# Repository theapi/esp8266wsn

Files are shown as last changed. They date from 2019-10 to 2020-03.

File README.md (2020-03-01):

# esp8266WSN

ESP8266 Wireless Sensor Network 

## Transmitter
Soil moisture sensors that transmit their data to the ESPNOW network.

- [Hardware](./transmitter/hardware)
- [Schematic](./transmitter/hardware/transmitter.pdf)
- [Software](./transmitter/software)

## Receiver
The receiver for the ESPNOW network, which sends the data to the network bridge.

- [Hardware](./receiver/hardware)
- [Software](./receiver/sfotware)

## Network Bridge
Connects the ESPNOW network to the WiFi network.

- [Software](./network_bridge)

## Monitor
Very basic UDP message listeners are provided in this repo:

- [C](./monitor/c)
- [php](./monitor/php)

A more sophisticated monitor is the [WSN Monitor](https://gitlab.com/theapi/wsn_monitor_sdl)

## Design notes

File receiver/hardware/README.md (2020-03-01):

# Hardware

- [Schematic](./kicad/receiver/receiver.pdf)
- [Datasheets](./datasheets)

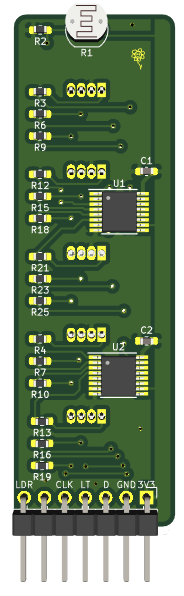
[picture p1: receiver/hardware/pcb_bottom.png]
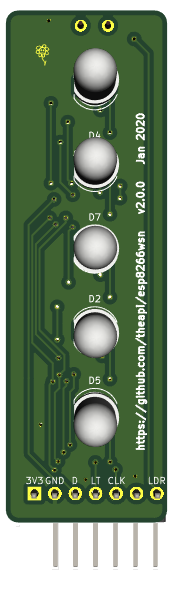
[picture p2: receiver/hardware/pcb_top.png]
 

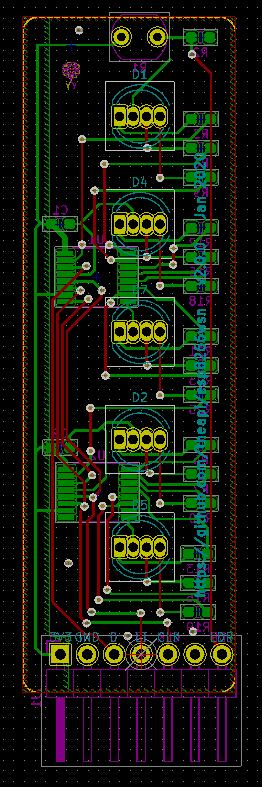
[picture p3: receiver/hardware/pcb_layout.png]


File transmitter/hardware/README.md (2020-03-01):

# Transmitter Hardware

[Schematic](./transmitter.pdf)

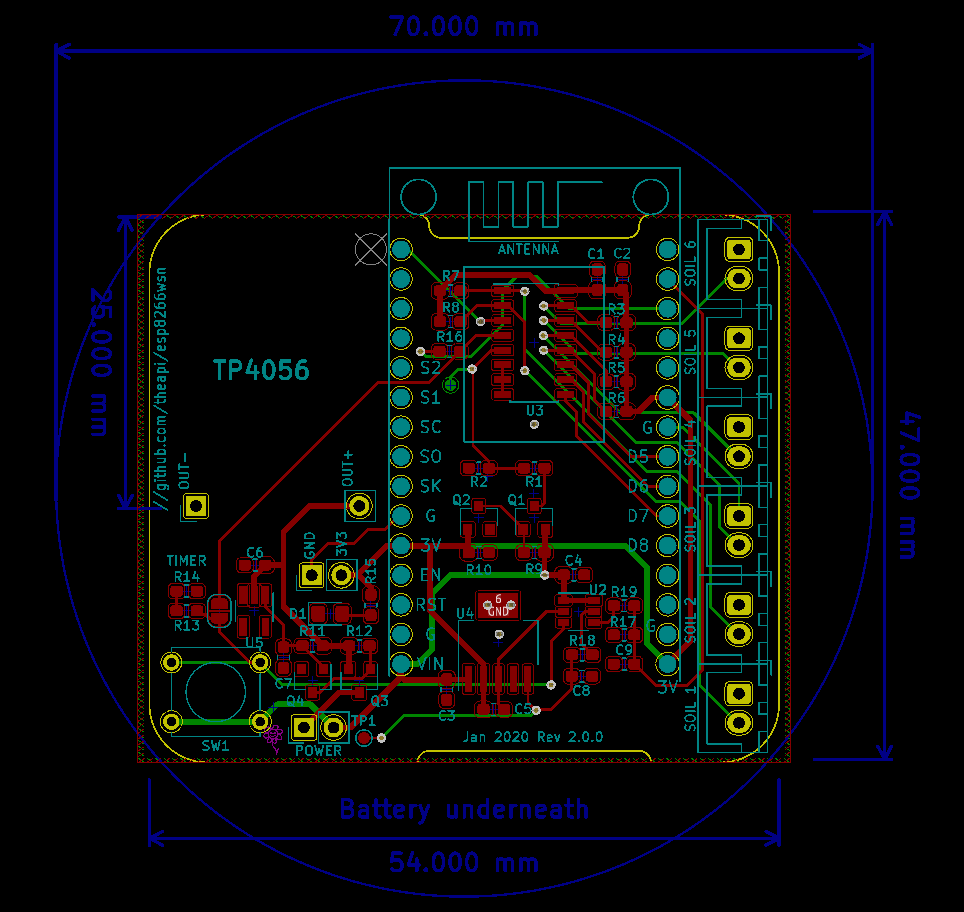
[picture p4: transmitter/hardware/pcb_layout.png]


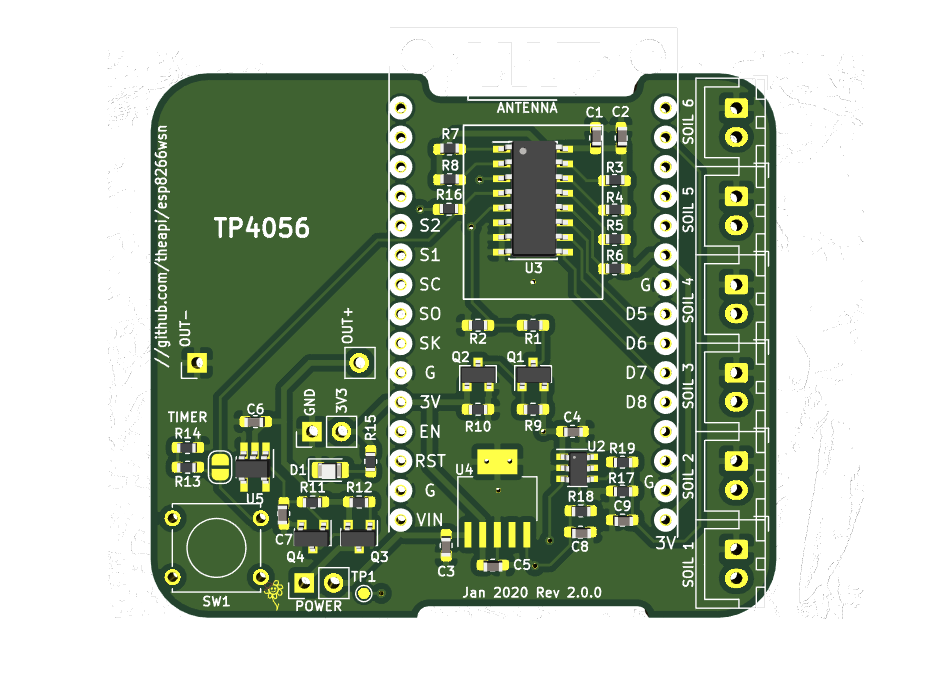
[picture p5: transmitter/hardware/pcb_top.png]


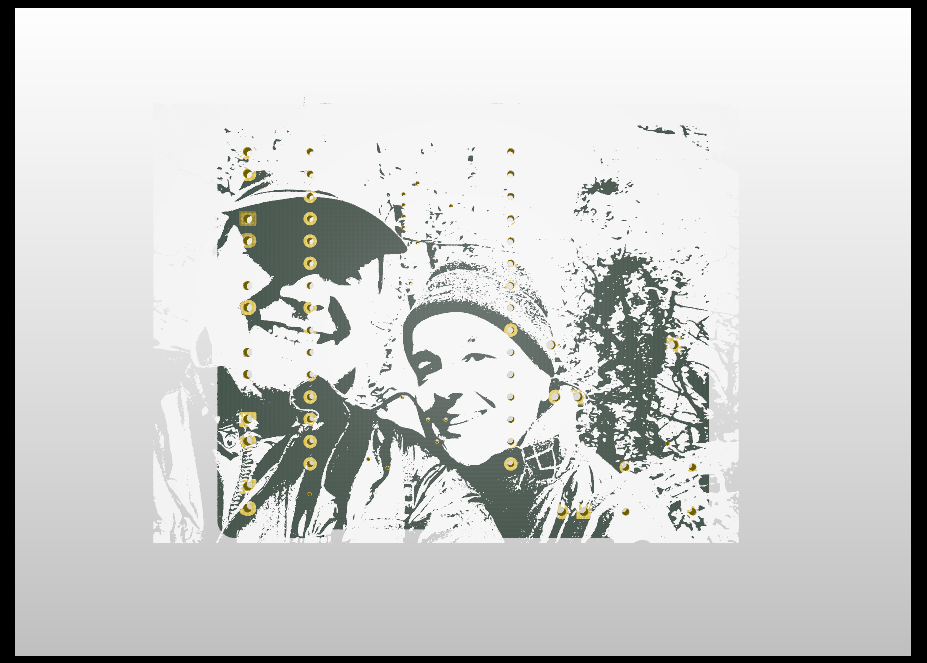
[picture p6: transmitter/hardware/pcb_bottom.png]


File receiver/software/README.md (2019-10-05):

# WSN Receiver

Listens for broadcast data on the ESPNow network.

## How to use

### Hardware Required

* Connection:

| Signal |NODE MCU| Master |
|---|---|---|
| SCLK | D5 | GPIO14 |
| MOSI | D7 | GPIO13 |
| CS | D8 | GPIO15 |
| GND | GND | GND |

### Configure the project

```
make menuconfig
```

* Set serial port under Serial Flasher Options.

### Build and Flash

Build the project and flash it to the board, then run monitor tool to view serial output:

```
make -j4 flash monitor
```

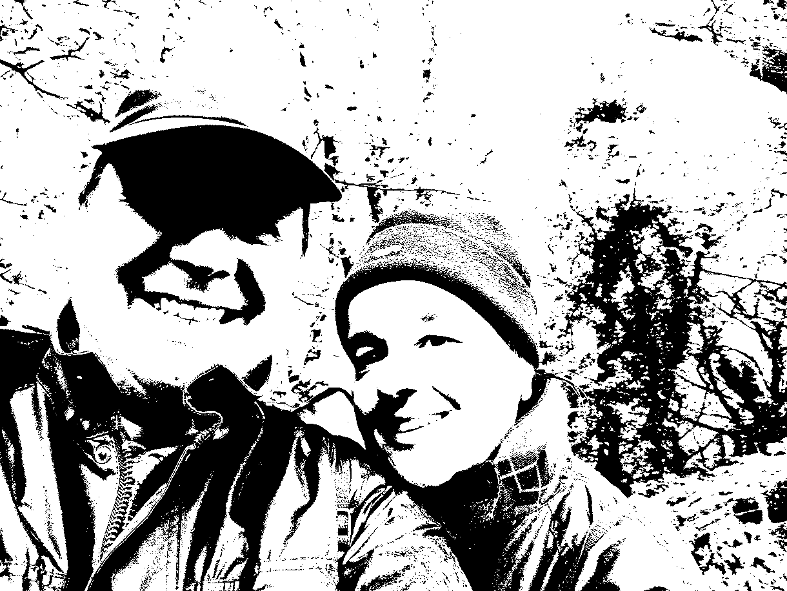
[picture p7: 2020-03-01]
transmitter/hardware/us_bw.png

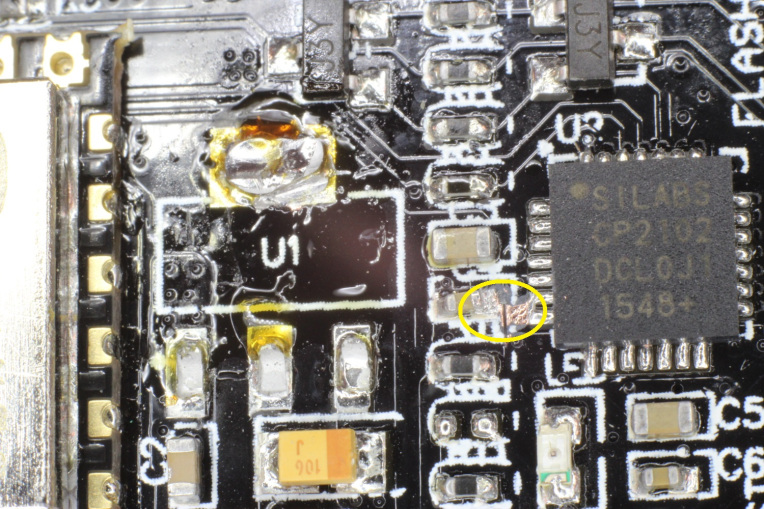
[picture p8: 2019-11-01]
transmitter/datasheets/nodemcu_low_power.jpg

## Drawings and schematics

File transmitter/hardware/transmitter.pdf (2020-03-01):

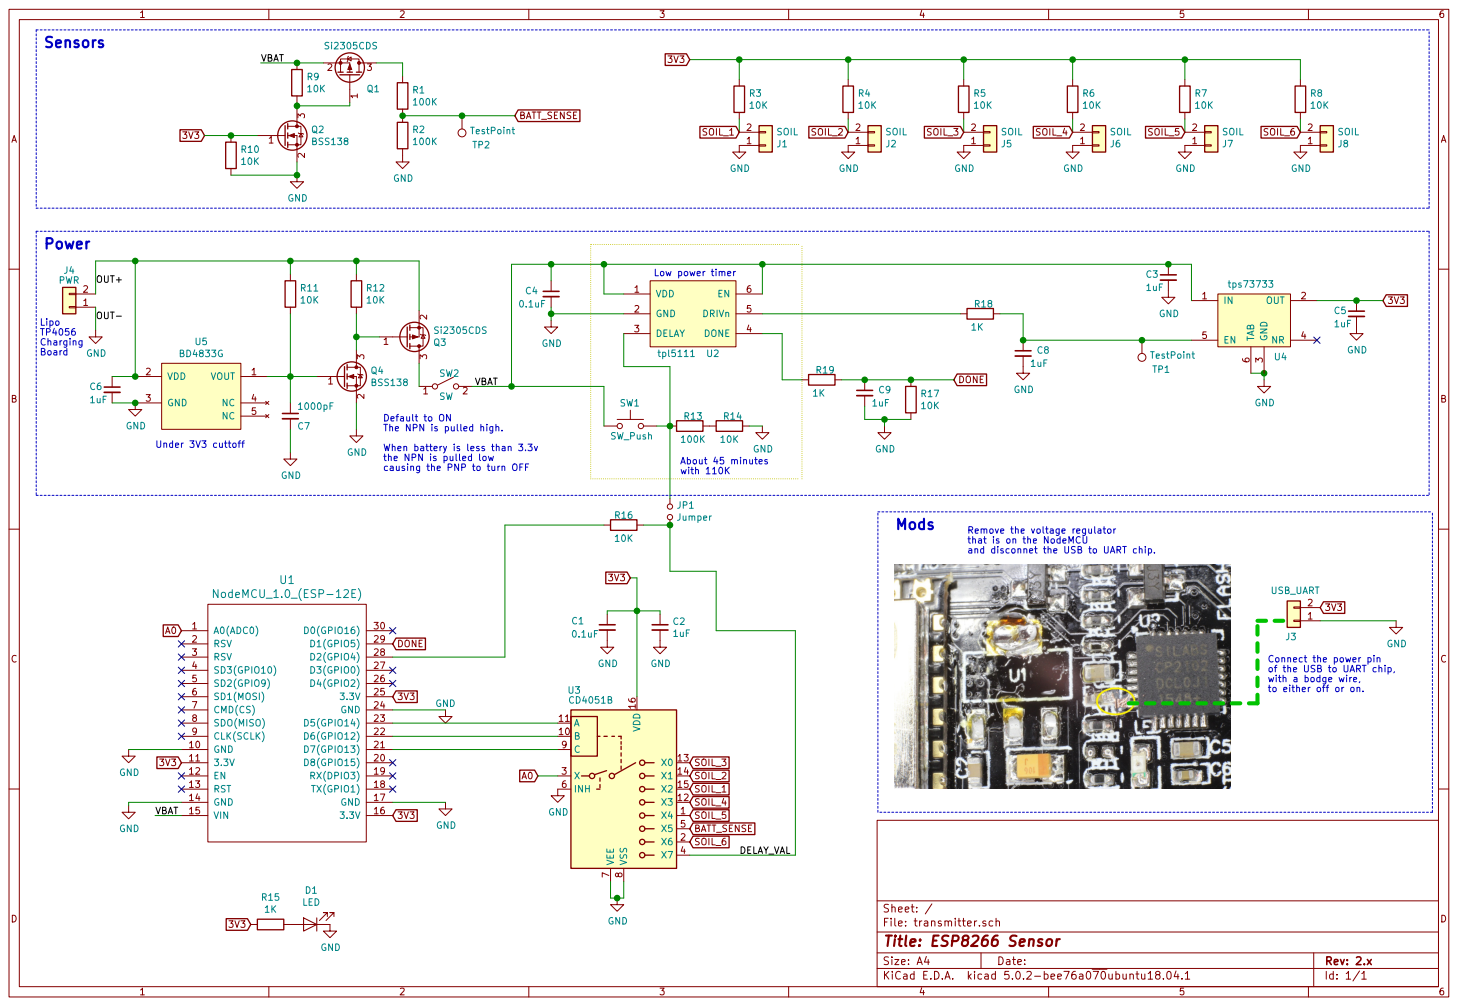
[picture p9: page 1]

2 3 Q3Si2305CDS R12
10KDefault to ON The NPN is pulled high.

When battery is less than 3.3v
the NPN is pulled low
causing the PNP to turn OFF

that is on the NodeMCU
and disconnet the USB to UART chip.

Connect the power pin
of the USB to UART chip,
with a bodge wire,
to either off or on.

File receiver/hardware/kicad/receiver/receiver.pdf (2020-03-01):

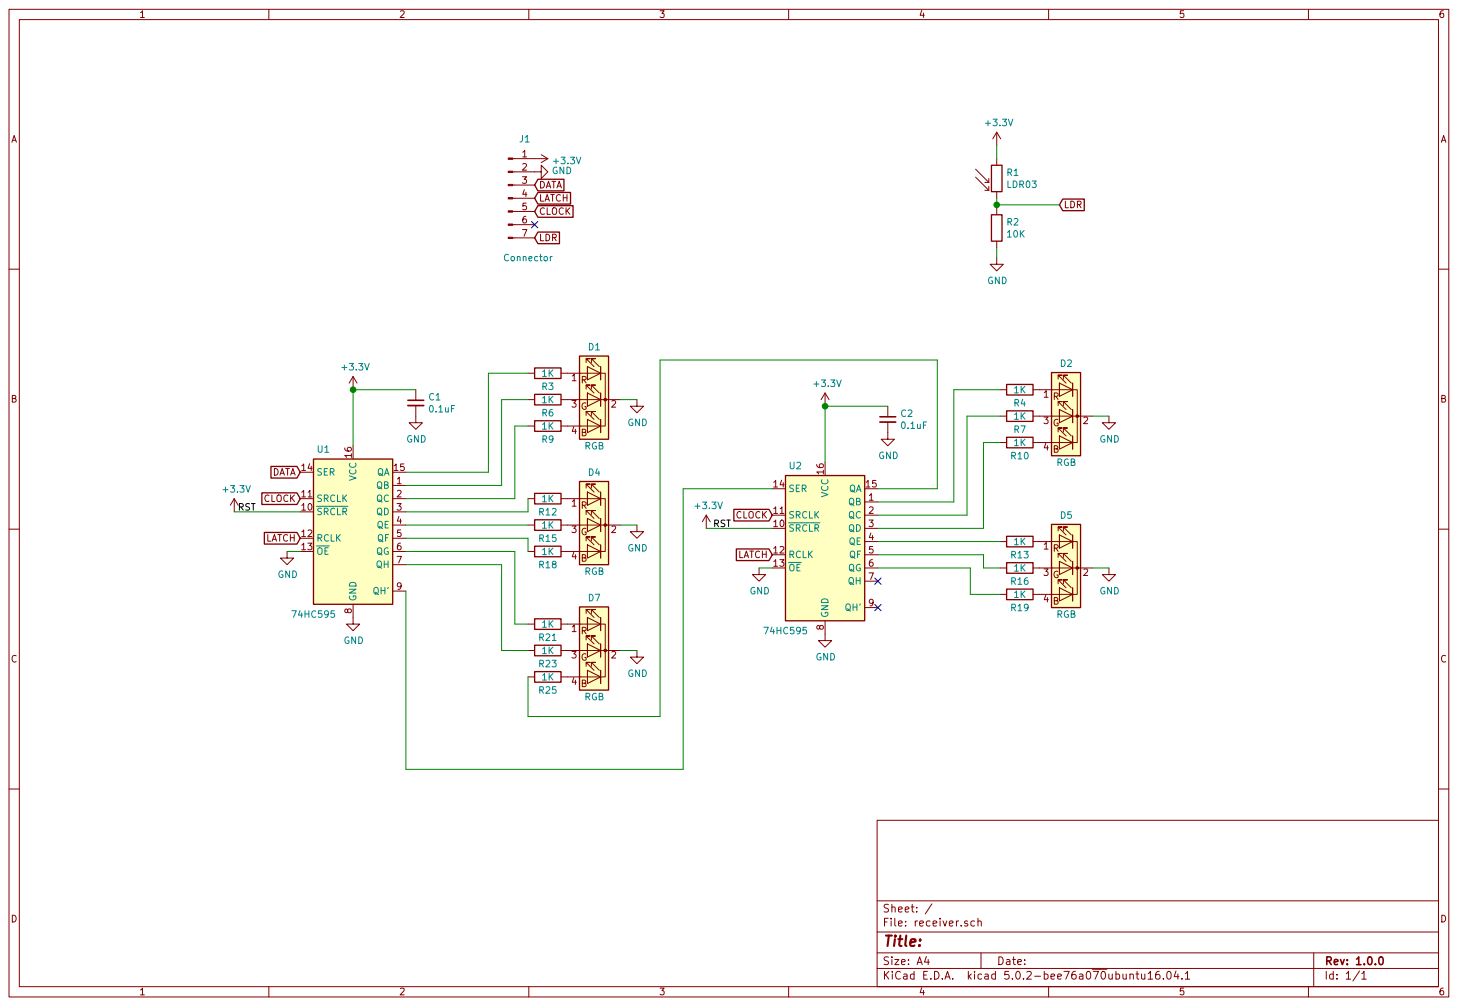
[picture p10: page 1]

Id: 1/1 Title: File: receiver.sch Sheet: /

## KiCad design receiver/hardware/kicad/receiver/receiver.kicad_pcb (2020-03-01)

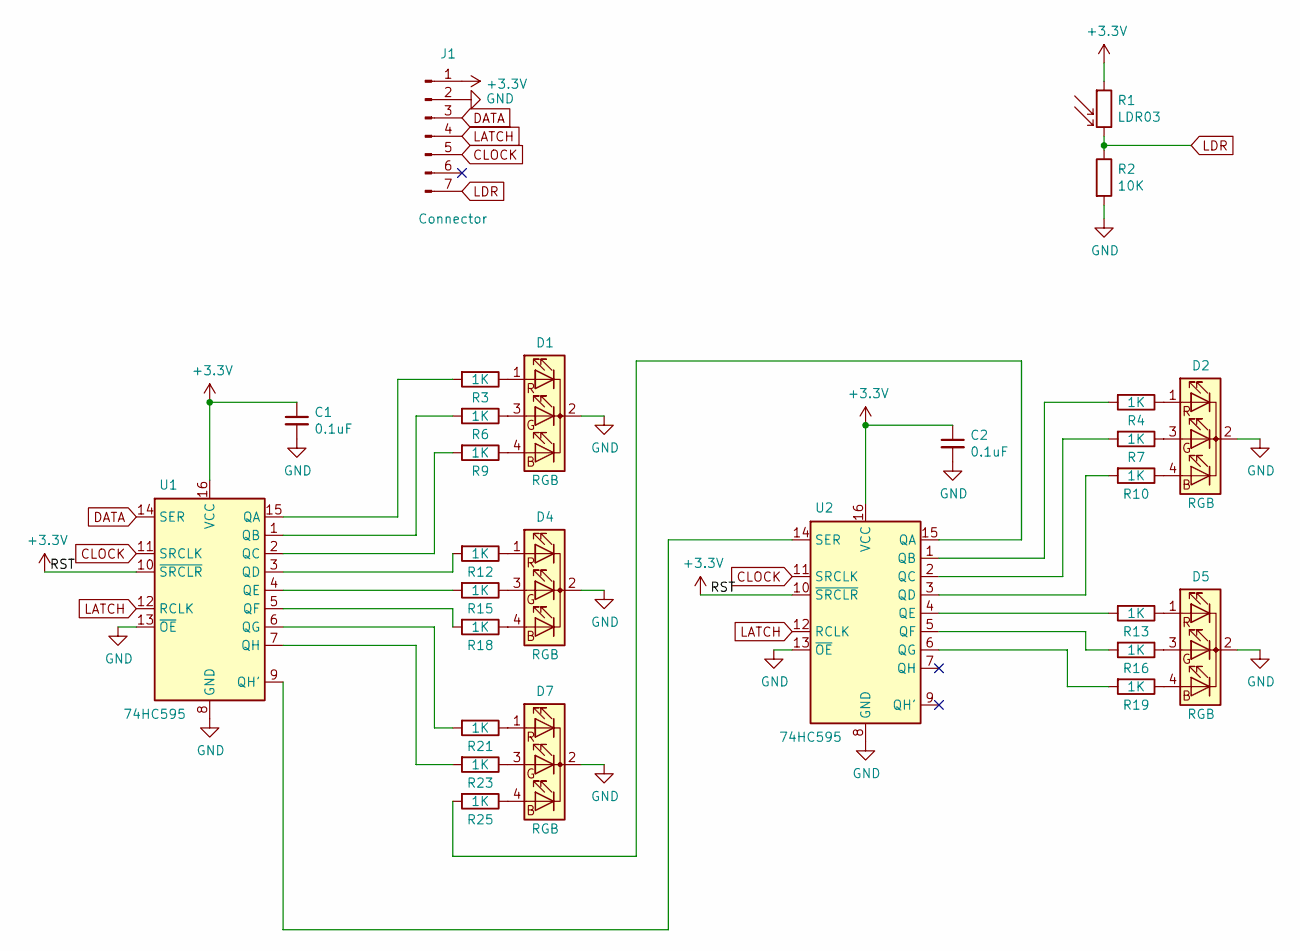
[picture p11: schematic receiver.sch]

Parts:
C1, C2: 0.1uF; C_0603_1608Metric_Pad1.05x0.95mm_HandSolder
D1, D2, D4, D5, D7: RGB; LED_D5.0mm-4_RGB
J1: Connector; PinHeader_1x07_P2.54mm_Horizontal
R1: LDR03; R_LDR_5.1x4.3mm_P3.4mm_Vertical
R2: 10K; R_0603_1608Metric_Pad1.05x0.95mm_HandSolder
R3, R4, R6, R7, R9, R10, R12, R13, R15, R16, R18, R19, R21, R23, R25: 1K; R_0603_1608Metric_Pad1.05x0.95mm_HandSolder
U1, U2: 74HC595; TSSOP-16_4.4x5mm_P0.65mm

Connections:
+3V3: C1.1, C2.1, J1.1, R1.1, U1.10 (~SRCLR), U1.16 (VCC), U2.10 (~SRCLR), U2.16 (VCC)
CLOCK: J1.5, U1.11 (SRCLK), U2.11 (SRCLK)
DATA: J1.3, U1.14 (SER)
GND: C1.2, C2.2, D1.2 (K), D2.2 (K), D4.2 (K), D5.2 (K), D7.2 (K), J1.2, R2.2, U1.8 (GND), U1.13 (~OE), U2.8 (GND), U2.13 (~OE)
LATCH: J1.4, U1.12 (RCLK), U2.12 (RCLK)
LDR: J1.7, R1.2, R2.1
unnamed: D1.1 (RA), R3.1
unnamed: D1.3 (GA), R6.1
unnamed: D1.4 (BA), R9.1
unnamed: D2.1 (RA), R4.1
unnamed: D2.3 (GA), R7.1
unnamed: D2.4 (BA), R10.1
unnamed: D4.1 (RA), R12.1
unnamed: D4.3 (GA), R15.1
unnamed: D4.4 (BA), R18.1
unnamed: D5.1 (RA), R13.1
unnamed: D5.3 (GA), R16.1
unnamed: D5.4 (BA), R19.1
unnamed: D7.1 (RA), R21.1
unnamed: D7.3 (GA), R23.1
unnamed: D7.4 (BA), R25.1
unnamed: R3.2, U1.15 (QA)
unnamed: R4.2, U2.1 (QB)
unnamed: R6.2, U1.1 (QB)
unnamed: R7.2, U2.2 (QC)
unnamed: R9.2, U1.2 (QC)
unnamed: R10.2, U2.3 (QD)
unnamed: R12.2, U1.3 (QD)
unnamed: R13.2, U2.4 (QE)
unnamed: R15.2, U1.4 (QE)
unnamed: R16.2, U2.5 (QF)
unnamed: R18.2, U1.5 (QF)
unnamed: R19.2, U2.6 (QG)
unnamed: R21.2, U1.6 (QG)
unnamed: R23.2, U1.7 (QH)
unnamed: R25.2, U2.15 (QA)
unnamed: U1.9 (QH'), U2.14 (SER)

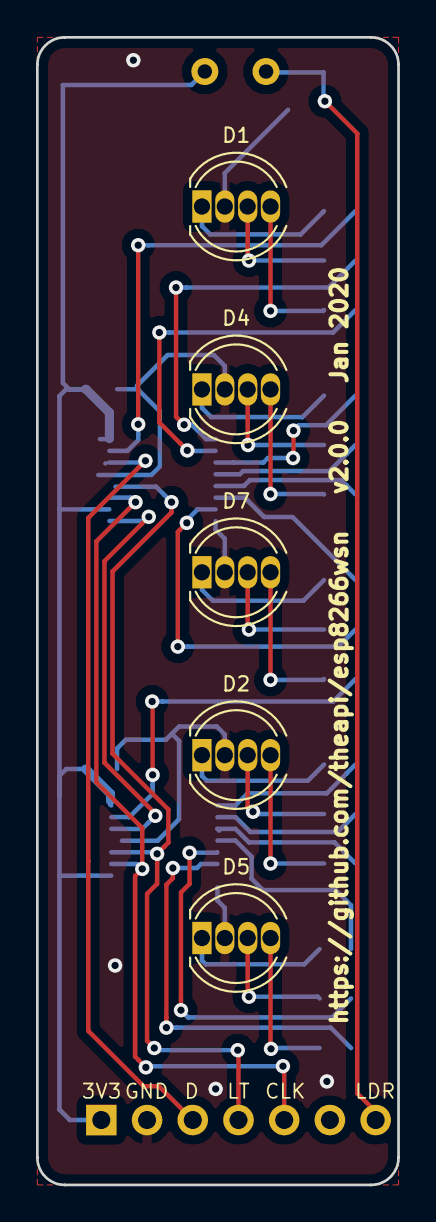
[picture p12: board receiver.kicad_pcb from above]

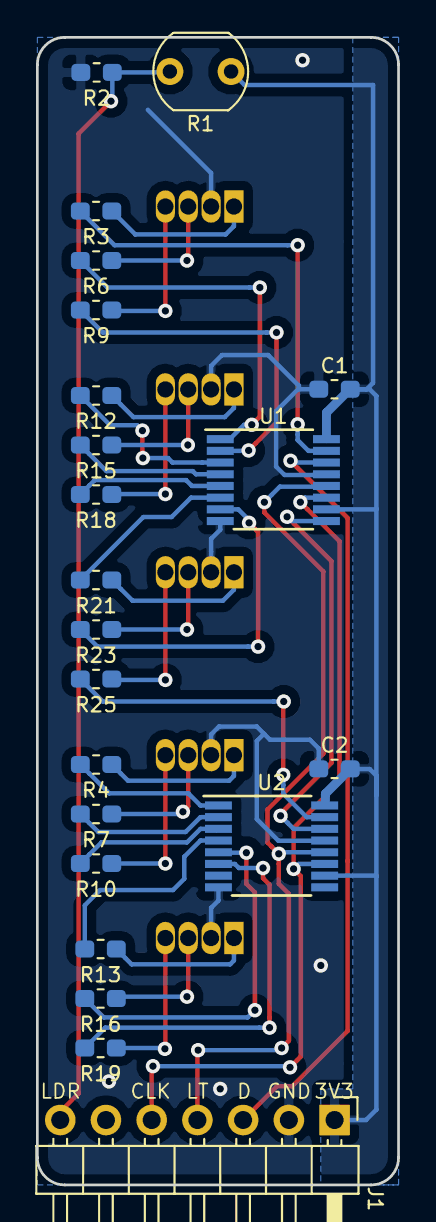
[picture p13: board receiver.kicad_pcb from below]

Board: 2 copper layers, 20.1 x 63.8 mm, 27 parts (22 on the bottom side), 37 nets.

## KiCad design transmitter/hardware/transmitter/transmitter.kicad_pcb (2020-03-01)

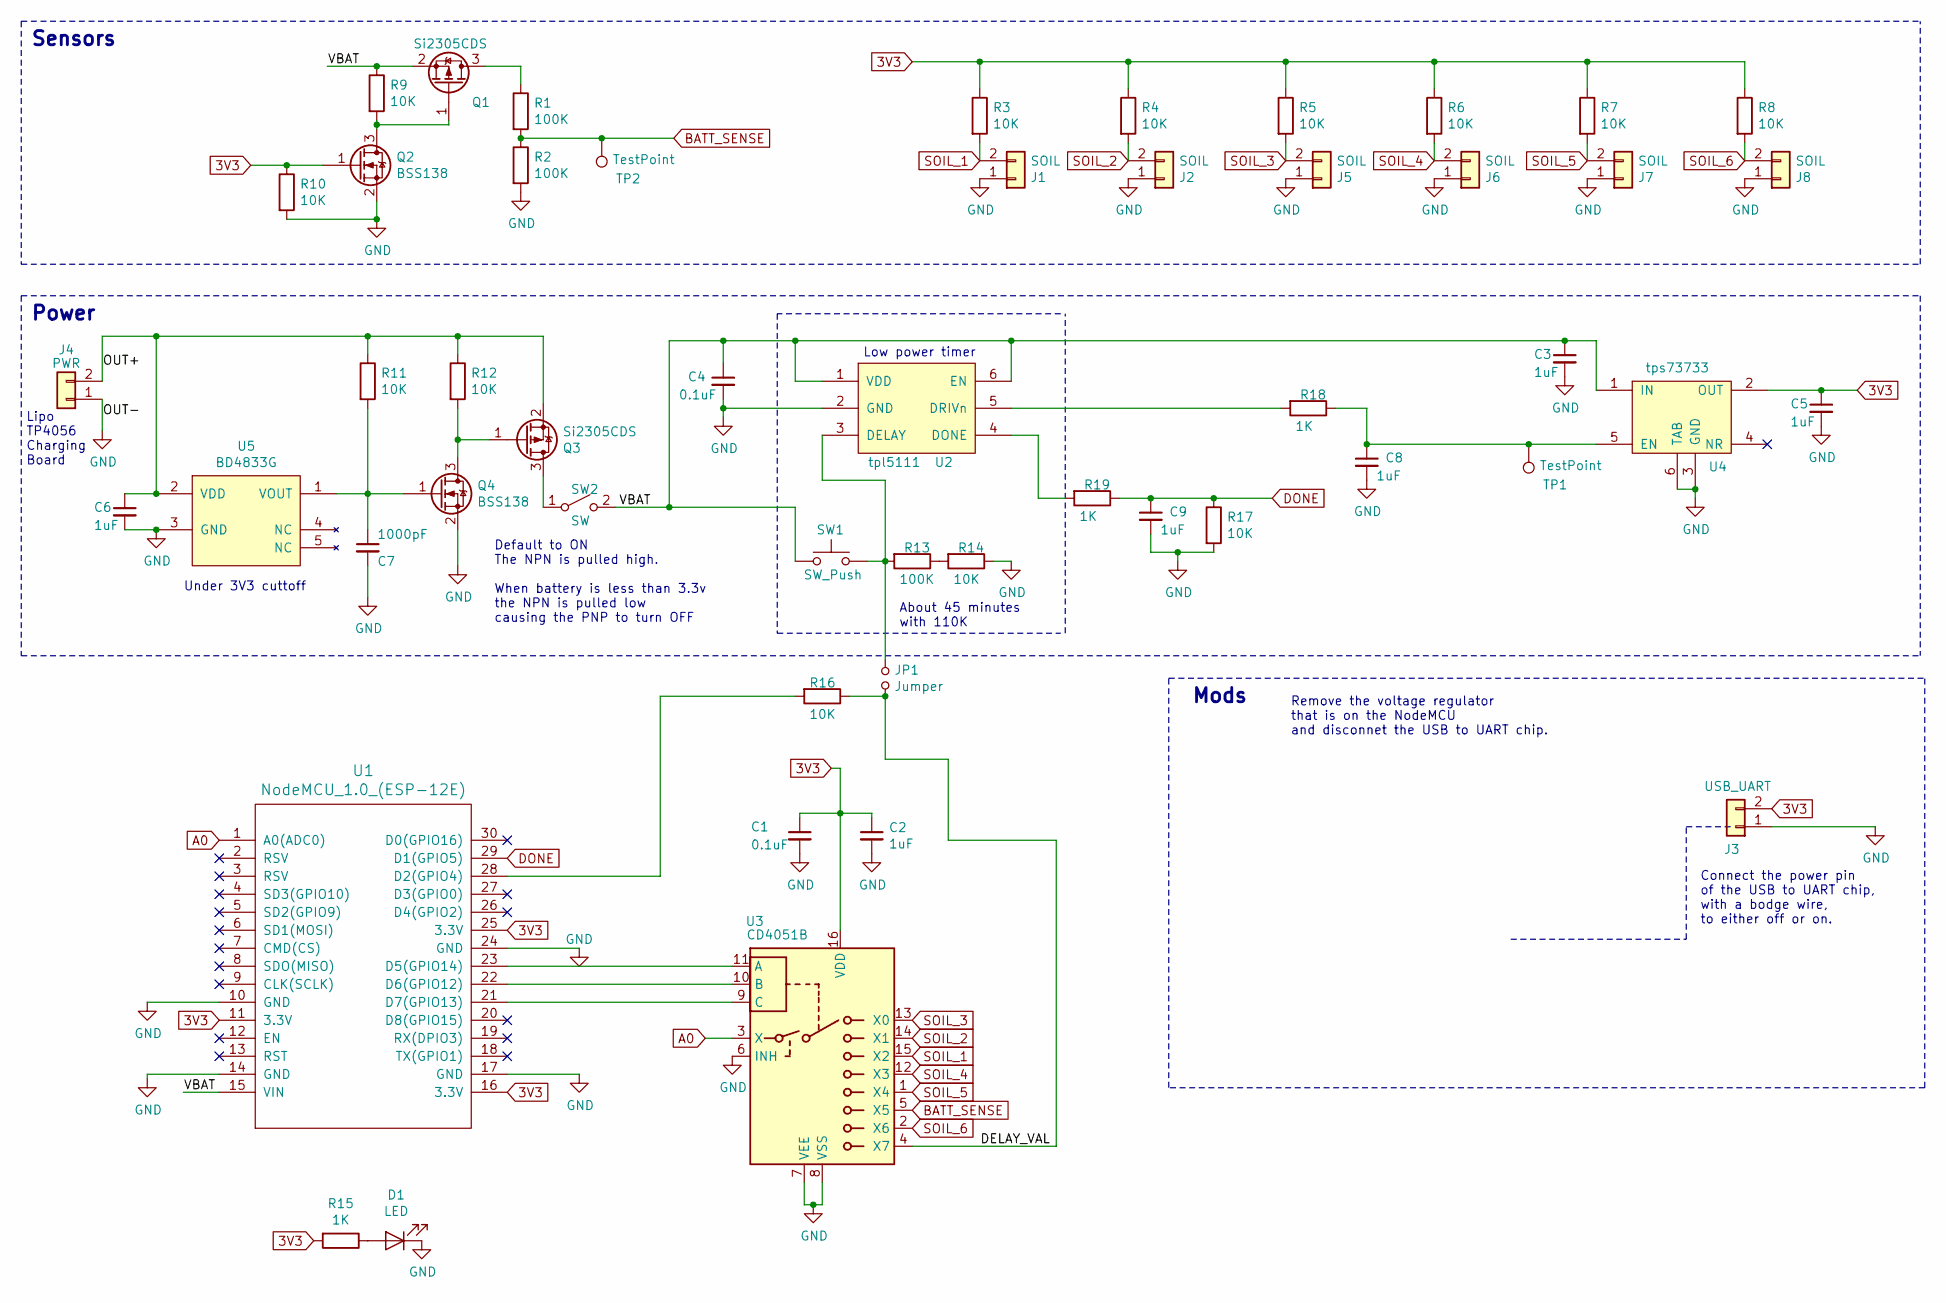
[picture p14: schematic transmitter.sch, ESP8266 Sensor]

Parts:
C1, C4: 0.1uF; C_0603_1608Metric_Pad1.05x0.95mm_HandSolder
C2, C3, C5, C6, C8, C9: 1uF; C_0603_1608Metric_Pad1.05x0.95mm_HandSolder
C7: 1000pF; C_0603_1608Metric_Pad1.05x0.95mm_HandSolder
D1: LED; LED_0805_2012Metric_Pad1.15x1.40mm_HandSolder
J1, J2, J5, J6, J7, J8: SOIL; JST_XH_B02B-XH-A_1x02_P2.50mm_Vertical
J3: USB_UART; PinHeader_1x02_P2.54mm_Vertical
J4: PWR; tp4056
JP1: Jumper; SolderJumper-2_P1.3mm_Open_RoundedPad1.0x1.5mm
Q1, Q3: Si2305CDS; SOT-23
Q2, Q4: BSS138; SOT-23
R1, R2, R13: 100K; R_0603_1608Metric_Pad1.05x0.95mm_HandSolder
R3, R4, R5, R6, R7, R8, R9, R10, R11, R12, R14, R16, R17: 10K; R_0603_1608Metric_Pad1.05x0.95mm_HandSolder
R15, R18, R19: 1K; R_0603_1608Metric_Pad1.05x0.95mm_HandSolder
SW1: SW_Push; SW_Tactile_Straight_KSL0Axx1LFTR
SW2: SW; PinHeader_1x02_P2.54mm_Vertical
TP1, TP2: TestPoint; TestPoint_Pad_D1.0mm
U1: NodeMCU_1.0_(ESP-12E); NodeMCU1.0(12-E)
U2: tpl5111; SOT-6-DDC
U3: CD4051B; SOIC-16_3.9x9.9mm_P1.27mm
U4: tps73733; SOT-223-6
U5: BD4833G; SOT-23-5_HandSoldering

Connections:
3V3: C1.1, C2.1, C5.1, J3.2, Q2.1 (G), R3.1, R4.1, R5.1, R6.1, R7.1, R8.1, R10.1, R15.2, U1.11 (3.3V), U1.16 (3.3V), U1.25 (3.3V), U3.16 (VDD), U4.2 (OUT)
/DELAY_VAL: JP1.1, R16.1, U3.4 (X7)
/OUT+: C6.1, J4.2, Q3.2 (S), R11.1, R12.1, U5.2 (VDD)
/VBAT: C3.1, C4.1, Q1.2 (S), R9.1, SW1.1, SW2.2 (B), U1.15 (VIN), U2.1 (VDD), U2.6 (EN), U4.1 (IN)
A0: U1.1 (A0(ADC0)), U3.3 (X)
BATT_SENSE: R1.2, R2.1, TP2.1, U3.5 (X5)
DONE: C9.1, R17.1, R19.1, U1.29 (D1(GPIO5))
GND: C1.2, C2.2, C3.2, C4.2, C5.2, C6.2, C7.2, C8.2, C9.2, D1.1 (K), J1.1, J2.1, J3.1, J4.1, J5.1, J6.1, J7.1, J8.1, Q2.2 (S), Q4.2 (S), R2.2, R10.2, R14.1, R17.2, U1.10 (GND), U1.14 (GND), U1.17 (GND), U1.24 (GND), U2.2 (GND), U3.6 (INH), U3.7 (VEE), U3.8 (VSS), U4.3 (GND), U4.6 (TAB), U5.3 (GND)
unnamed: C7.1, Q4.1 (G), R11.2, U5.1 (VOUT)
unnamed: C8.1, R18.1, TP1.1, U4.5 (EN)
unnamed: D1.2 (A), R15.1
unnamed: JP1.2, R13.2, SW1.2, U2.3 (DELAY)
unnamed: Q1.1 (G), Q2.3 (D), R9.2
unnamed: Q1.3 (D), R1.1
unnamed: Q3.1 (G), Q4.3 (D), R12.2
unnamed: Q3.3 (D), SW2.1 (A)
unnamed: R13.1, R14.2
unnamed: R16.2, U1.28 (D2(GPIO4))
unnamed: R18.2, U2.5 (DRIVn)
unnamed: R19.2, U2.4 (DONE)
unnamed: U1.21 (D7(GPIO13)), U3.9 (C)
unnamed: U1.22 (D6(GPIO12)), U3.10 (B)
unnamed: U1.23 (D5(GPIO14)), U3.11 (A)
SOIL_1: J1.2, R3.2, U3.15 (X2)
SOIL_2: J2.2, R4.2, U3.14 (X1)
SOIL_3: J5.2, R5.2, U3.13 (X0)
SOIL_4: J6.2, R6.2, U3.12 (X3)
SOIL_5: J7.2, R7.2, U3.1 (X4)
SOIL_6: J8.2, R8.2, U3.2 (X6)

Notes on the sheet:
Remove the voltage regulator that is on the NodeMCU and disconnet the USB to UART chip.
Connect the power pin of the USB to UART chip, with a bodge wire, to either off or on.
Power
Sensors
Mods
Lipo TP4056 Charging Board
Default to ON The NPN is pulled high. When battery is less than 3.3v the NPN is pulled low causing the PNP to turn OFF
About 45 minutes with 110K
Low power timer
Under 3V3 cuttoff

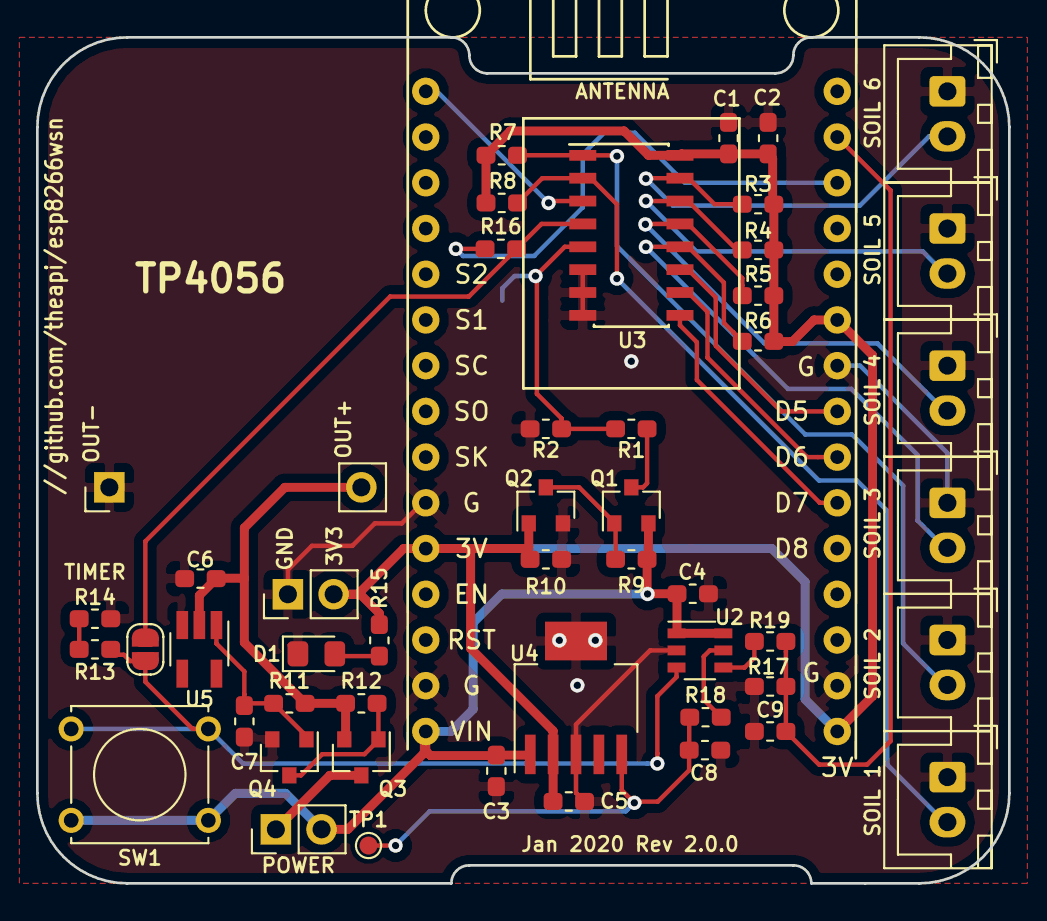
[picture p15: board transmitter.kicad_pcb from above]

Board: 2 copper layers, 54.0 x 47.0 mm, 51 parts (1 on the bottom side), 29 nets.

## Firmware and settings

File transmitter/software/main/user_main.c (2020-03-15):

#include <string.h>
#include "crc.h"
#include "esp_event_loop.h"
#include "esp_log.h"
#include "esp_now.h"
#include "esp_sleep.h"
#include "esp_system.h"
#include "esp_wifi.h"
#include "freertos/FreeRTOS.h"
#include "freertos/timers.h"
#include "payload.h"
#include "tcpip_adapter.h"

#include "driver/adc.h"
#include "driver/gpio.h"

#define PIN_DONE  5  // D1 (nodemcu)
#define PIN_MULTIPLEX_A 14 // D5 (nodemcu)
#define PIN_MULTIPLEX_B 12 // D6 (nodemcu)
#define PIN_MULTIPLEX_C 13 // D7 (nodemcu)
#define GPIO_OUTPUT_PIN_SEL ((1ULL<<PIN_MULTIPLEX_A) | (1ULL<<PIN_MULTIPLEX_B) | (1ULL<<PIN_MULTIPLEX_C) | (1ULL<<PIN_DONE) )
#define DELAY_SECONDS 40 * 60 // (36.26815) How long between each transmission (harware defined by resistors)

static const char *TAG = "transmitter";

static uint8_t app_broadcast_mac[ESP_NOW_ETH_ALEN] = {0xFF, 0xFF, 0xFF,
                                                      0xFF, 0xFF, 0xFF};
/* Global send buffer. */
uint8_t buffer[sizeof(PAYLOAD_sensor_t)] = {0};


/* WiFi should start before using ESPNOW */
static esp_err_t app_wifi_init(void) {
  tcpip_adapter_init();

  if (esp_event_loop_init(NULL, NULL) != ESP_OK) {
    ESP_LOGE(TAG, "Failed: esp_event_loop_init");
    return ESP_FAIL;
  }

  wifi_init_config_t cfg = WIFI_INIT_CONFIG_DEFAULT();
  cfg.nvs_enable = 0;
  if (esp_wifi_init(&cfg) != ESP_OK) {
    ESP_LOGE(TAG, "Failed: esp_wifi_init");
    return ESP_FAIL;
  }

  if (esp_wifi_set_storage(WIFI_STORAGE_RAM) != ESP_OK) {
    ESP_LOGE(TAG, "Failed: esp_wifi_set_storage");
    return ESP_FAIL;
  }

  if (esp_wifi_set_mode(WIFI_MODE_STA) != ESP_OK) {
    ESP_LOGE(TAG, "Failed: esp_wifi_set_mode");
    return ESP_FAIL;
  }

  if (esp_wifi_start() != ESP_OK) {
    ESP_LOGE(TAG, "Failed: esp_wifi_start");
    return ESP_FAIL;
  }

  /* In order to simplify example, channel is set after WiFi started.
   * This is not necessary in real application if the two devices have
   * been already on the same channel.
   */
  if (esp_wifi_set_channel(CONFIG_ESPNOW_CHANNEL, 0) != ESP_OK) {
    ESP_LOGE(TAG, "Failed: esp_wifi_set_channel");
    return ESP_FAIL;
  }

  return ESP_OK;
}

static esp_err_t app_espnow_init(void) {
  /* Initialize ESPNOW and register sending and receiving callback function. */
  if (esp_now_init() != ESP_OK) {
    ESP_LOGE(TAG, "Failed: esp_now_init");
    return ESP_FAIL;
  }

  /* Add broadcast peer information to peer list. */
  esp_now_peer_info_t *peer = malloc(sizeof(esp_now_peer_info_t));
  if (peer == NULL) {
    ESP_LOGE(TAG, "Malloc peer information fail");
    esp_now_deinit();
    return ESP_FAIL;
  }
  memset(peer, 0, sizeof(esp_now_peer_info_t));
  peer->channel = CONFIG_ESPNOW_CHANNEL;
  peer->ifidx = ESP_IF_WIFI_STA;
  peer->encrypt = false;
  memcpy(peer->peer_addr, app_broadcast_mac, ESP_NOW_ETH_ALEN);

  esp_err_t ret = esp_now_add_peer(peer);
  free(peer);
  if (ret != ESP_OK) {
    //ESP_LOGE(TAG, "Failed: esp_now_add_peer");
    return ESP_FAIL;
  }

  return ESP_OK;
}

static void setupGPIO() {
    gpio_config_t io_conf;
    //disable interrupt
    io_conf.intr_type = GPIO_INTR_DISABLE;
    //set as output mode
    io_conf.mode = GPIO_MODE_OUTPUT;
    //bit mask of the pins that you want to set,e.g.GPIO15/16
    io_conf.pin_bit_mask = GPIO_OUTPUT_PIN_SEL;
    //disable pull-down mode
    io_conf.pull_down_en = 0;
    //disable pull-up mode
    io_conf.pull_up_en = 0;
    //configure GPIO with the given settings
    gpio_config(&io_conf);
}

/* Selects the ADC multiplexer channel. */
static void multiplexer_set_channel(uint8_t chan) {
  // Set the levels of the multiplexer channel
  // from the bit values of the given channel number.
  gpio_set_level(PIN_MULTIPLEX_A, (chan >> 0) & 0x01);
  gpio_set_level(PIN_MULTIPLEX_B, (chan >> 1) & 0x01);
  gpio_set_level(PIN_MULTIPLEX_C, (chan >> 2) & 0x01);
}

/**
 * Mapping for hardware inputs to multplexer channels:
 * chan 0 = input 4
 * chan 1 = input 5
 * chan 2 = input 6
 * chan 3 = input 3
 * chan 4 = input 2
 * chan 5 = battery
 * chan 6 = input 1
 * chan 7 = not connected
 */
static void readings_get(uint16_t adc[PAYLOAD_ADC_NUM]) {
  uint16_t map[8] = {4, 5, 6, 3, 2, 0, 1, 7};
  for (uint16_t i = 0; i < PAYLOAD_ADC_NUM; i++) {
    multiplexer_set_channel(i);
    if (i < 8) {
      uint16_t j = map[i];
      adc_read(&adc[j]);
      adc_read(&adc[j]);
    }
  }
}

esp_err_t readings_init() {
  adc_config_t adc_config;
  adc_config.mode = ADC_READ_TOUT_MODE;
  adc_config.clk_div = 8;  // 80MHz/clk_div = 10MHz
  if (adc_init(&adc_config) != ESP_OK) {
    return ESP_FAIL;
  }

  return ESP_OK;
}

/**
 * Battery id adc[0]
 * raw 568 = 4064 mV (on the battery)
 * so 1 = 7.154929577 mV
 */
static uint16_t adc2Batt(uint16_t val) {
  return val * 7.154929577;
}

/* Prepare ESPNOW data to be sent. */
static void data_prepare() {
  static uint8_t msg_id = 0;

  /* Map the buffer to the struct for ease of manipulation */
  PAYLOAD_sensor_t *buf = (PAYLOAD_sensor_t *)buffer;

  buf->payload_type = PAYLOAD_TYPE;

  //esp_read_mac(buf->mac, ESP_MAC_WIFI_STA);
  esp_efuse_mac_get_default(buf->mac);

  buf->message_id = ++msg_id;
  buf->crc = 0;
  readings_get(buf->adc);
  buf->adc[7] = buf->adc[0]; // Raw batt value to the unconnected adc val.
  buf->batt = adc2Batt(buf->adc[0]);
  buf->delay = DELAY_SECONDS;

  buf->crc =
      crc16_le(UINT16_MAX, (uint8_t const *)buf, sizeof(PAYLOAD_sensor_t));
  ESP_LOGI(TAG, "Mac: %02X:%02X:%02X:%02X:%02X:%02X",
                buf->mac[0], buf->mac[1], buf->mac[2], buf->mac[3], buf->mac[4], buf->mac[5]);
  ESP_LOGI(TAG, "Delay: %d, msg_id: %d, BATT: %d, CRC %d, ADC_0: %d, ADC_1: %d, ADC_2: %d, ADC_3: %d, ADC_4: %d, ADC_5: %d, ADC_6: %d",
                buf->delay, buf->message_id, buf->batt, buf->crc,
                buf->adc[0], buf->adc[1], buf->adc[2], buf->adc[3], buf->adc[4], buf->adc[5], buf->adc[6]);
}

static esp_err_t transmit() {
  ESP_LOGI(TAG, "RAM left %d bytes", esp_get_free_heap_size());

  /* Start sending broadcast ESPNOW data. */
  if (esp_now_send(app_broadcast_mac, buffer, sizeof(PAYLOAD_sensor_t)) !=
      ESP_OK) {
    ESP_LOGE(TAG, "Send error");
    return ESP_FAIL;
  } else {
    ESP_LOGI(TAG, "Sent");
    return ESP_OK;
  }
  return ESP_FAIL;
}

void app_main() {
  setupGPIO();

  // Ensure the power is kept on
  gpio_set_level(PIN_DONE, 0);

  if (readings_init() != ESP_OK) {
    esp_restart();
  }

  if (app_wifi_init() != ESP_OK) {
    esp_restart();
  }
  if (app_espnow_init() != ESP_OK) {
    esp_restart();
  }

  data_prepare();
  transmit();

  // Turn off the power. (total power on time = 39ms)
  gpio_set_level(PIN_DONE, 1);

  // Shouldn't get here.
  // Just in case to stop many transmissions.
  vTaskDelay(DELAY_SECONDS * 1000 / portTICK_RATE_MS);
  esp_restart();
}

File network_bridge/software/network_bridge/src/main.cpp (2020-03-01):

/**
 * To subscribe to the UDP data: listen for broadcasts on 239.0.0.58 port 12345
 */

#include <Arduino.h>
#include <ESP8266WiFi.h>
#include <WiFiUdp.h>
#include "config.h"
#include "payload.h"
#include "sensor.h"

#define UDP_DELAY_EXTRA 2 // Number of seconds extra to wait to hear from the sensor again.

// A UDP instance to let us send and receive packets over UDP
WiFiUDP Udp;

// Multicast declarations
IPAddress ipMulti(239, 0, 0, 58);
unsigned int portMulti = 12345;      // local port to listen on


WiFiClient espClient;

uint8_t rx_buffer[SENSOR_BUFFER_SIZE];
uint8_t rx_buffer_index = 0;
uint8_t payload_length = 0;
const long ping_interval = 2000;
unsigned long ping_last = 0;

enum State {
  ST_WAITING,
  ST_LENGTH,
  ST_HEADER_VALIDATION,
  ST_DATA
};
State payload_state = ST_WAITING;

void setup() {
  Serial.begin(115200);
  Serial.println();

  WiFi.begin(ssid, password);
  Serial.print("\nConnecting to "); Serial.println(ssid);
  uint8_t i = 0;
  while (WiFi.status() != WL_CONNECTED && i++ < 20) delay(500);
  if(i == 21){
    Serial.print("Could not connect to"); Serial.println(ssid);
    delay(5000);
    ESP.restart();
  }

  Serial.println(WiFi.localIP().toString());
  Serial.println("Ready! Listen for UDP broadcasts on 239.0.0.58 port 12345");
}

void udpBroadcastPayload(uint8_t num) {
  Sensor_t sensor = SensorGetByNumber(num);
  if (sensor.size != 0) {
    Serial.printf("broadcast: %d, mac: %02X,  msgid: %d\n", sensor.num, sensor.payload.mac[0], sensor.payload.message_id);
    Udp.beginPacketMulticast(ipMulti, portMulti, WiFi.localIP());

    // Send the contents of the original raw buffer.
    Udp.write(sensor.raw, sensor.size);

    Udp.endPacket();
    Udp.stop();
  }
}

void udpPing() {
  unsigned long now = millis();
  for (uint8_t i = 0; i < SENSOR_NUM; i++) {
    Sensor_t sensor = SensorGetByNumber(i);
    if (now - sensor.last > (sensor.payload.delay + UDP_DELAY_EXTRA) * 1000UL) {
      // Old data don't send it.
    } else if (sensor.payload.message_id != sensor.previous.message_id) {
      Serial.printf("Ping: %d\n", i);
      udpBroadcastPayload(i);
    }
  }
}

void loop() {
  unsigned long currentMillis = millis();

  // Read the data from the receiver.
  while (Serial.available()) {
    // get the new byte:
    uint8_t c = (uint8_t) Serial.read();
    //Serial.println(c, HEX);

    switch (payload_state) {
      case ST_WAITING:
        // Wait for the payload header.
        if (c == 0xAA) {
          rx_buffer_index = 0;
          // Clear the rx buffer, ready for new data.
          memset(rx_buffer, 0, SENSOR_BUFFER_SIZE);
          payload_state = ST_LENGTH;
        } else {
          // Passthru other serial messages.
          //Serial.print(char(c));
        }
        break;

      case ST_LENGTH:
        payload_length = c;
        payload_state = ST_HEADER_VALIDATION;
        break;

      case ST_HEADER_VALIDATION:
        // Next byte is the end of the header.
        if (c == 0xAA) {
          payload_state = ST_DATA;
        } else {
          // Not a real header, so start again.
          payload_state = ST_WAITING;
        }
        break;

      case ST_DATA:
        rx_buffer[rx_buffer_index++] = c;
        if (rx_buffer_index == payload_length) {
          Sensor_t sensor = SensorPopulate(rx_buffer, payload_length);
          udpBroadcastPayload(sensor.num);
//          Serial.printf("Sensor: num %d, prev: %d, msg_id %d, last %d, size %d\n",
//            sensor.num, sensor.previous.message_id, sensor.payload.message_id, sensor.last, sensor.size);

          payload_state = ST_WAITING;
        }
        break;
    }
  }


  if ( (payload_state == ST_WAITING) && (currentMillis - ping_last >= ping_interval) ) {
    ping_last = currentMillis;
    udpPing();
  }

}

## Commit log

2019-10-19 Transmitter with sensor payload
2019-10-26 Light sensor in its own file
2019-10-27 ADC readings on the sensor
2019-10-30 Hardware device id
2019-11-01 Mac address instead of device id
2019-11-01 Initial PCB layaout
    [transmitter.sch]
2019-11-01 All connected
    [transmitter.kicad_pcb]
2019-11-01 Power traces
    [transmitter.kicad_pcb, transmitter.sch]
2019-11-02 Multiple soil sensors
    [transmitter.sch]
2019-11-02 JST connectors
    [transmitter.kicad_pcb, transmitter.sch]
2019-11-03 Vin & battery straps
    [transmitter.kicad_pcb, transmitter.sch]
2019-11-03 battery straps
    [transmitter.kicad_pcb]
2019-11-04 Moved the ldo
    [transmitter.kicad_pcb]
2019-11-04 nodemcu footprint
    [transmitter.kicad_pcb]
2019-11-05 Alternate LDO
    [transmitter.kicad_pcb, transmitter.sch]
2019-11-05 Corrected the Nodemcu footprint
    [transmitter.kicad_pcb]
2019-11-13 Battery calibration
2019-11-13 Sensor power pin & mapping to the labels
2019-11-13 Battery in mV
2019-11-19 Sleep again if the battery is too low
    [user_main.c]
2019-11-23 Batt calibration
2019-12-01 UART out of the receiver
2019-12-01 Default serial output for ADC values
2019-12-11 One led per sensor
2019-12-12 Clear a sensor's led if not heard from for a while.
2019-12-14 Multiple sensors
2019-12-15 Handle line buffer correctly
    [network_bridge.ino]
2019-12-24 Remove old sensors
2019-12-29 Corrected the delay time
    [network_bridge.ino]
2019-12-30 Disabled initial battery check, to find cause of not waking after 10 seconds
2020-01-01 Lower power turn off
    [transmitter.sch]
2020-01-06 External low power timer
    [transmitter.sch]
2020-01-06 Low power
    [transmitter.sch]
2020-01-08 Assigned footprints
    [transmitter.sch]
2020-01-08 Start of placement
    [transmitter.kicad_pcb, transmitter.sch]
2020-01-08 Smaller multiplexer
    [transmitter.kicad_pcb, transmitter.sch]
2020-01-08 Wired multiplexer
    [transmitter.kicad_pcb]
2020-01-09 TPL5111 footprint
    [transmitter.kicad_pcb]
2020-01-09 Wired the low voltage cutoff
    [transmitter.kicad_pcb]
2020-01-11 Power led
    [transmitter.kicad_pcb, transmitter.sch]
2020-01-11 External timer to remove power
2020-01-11 Swapped sensor polarity
    [transmitter.kicad_pcb, transmitter.sch]
2020-01-11 Graphic silkscreen
    [transmitter.kicad_pcb]
2020-01-12 Receiver LED display
    [receiver.kicad_pcb, receiver.sch]
2020-01-12 Initial layout
    [receiver.kicad_pcb, receiver.sch]
2020-01-14 Fit beneath the NodeMCU
    [receiver.kicad_pcb]
2020-01-17 Timer resistors on the bottom
    [transmitter.kicad_pcb]
2020-01-17 Measure the delay time
    [transmitter-B.Cu.gbl, transmitter-B.Mask.gbs, transmitter-B.SilkS.gbo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]
2020-01-18 Optionally measure timer resistors
    [transmitter-B.Cu.gbl, transmitter-B.Mask.gbs, transmitter-B.SilkS.gbo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]
2020-01-18 Rotated timer IC
    [transmitter-B.Cu.gbl, transmitter-B.Mask.gbs, transmitter-B.SilkS.gbo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]
2020-01-21 tpl5111 layout tweak
    [transmitter.kicad_pcb, transmitter.sch]
2020-01-21 Fit within 70mm circle
    [transmitter-B.Cu.gbl, transmitter-B.Mask.gbs, transmitter-B.SilkS.gbo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]
2020-01-22 Filters on the timer lines
    [transmitter.sch]
2020-01-27 Faster filter
    [transmitter.sch]
2020-02-17 5 sensors
2020-03-01 Battery calibration & timer delay
2020-03-15 LEDs dependendant on the ambiant light
2020-03-15 Calibration on the battery
